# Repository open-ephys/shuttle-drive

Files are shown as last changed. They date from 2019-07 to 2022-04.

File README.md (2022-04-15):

# Shuttle-drive, the next gen. tetrode drive implant 

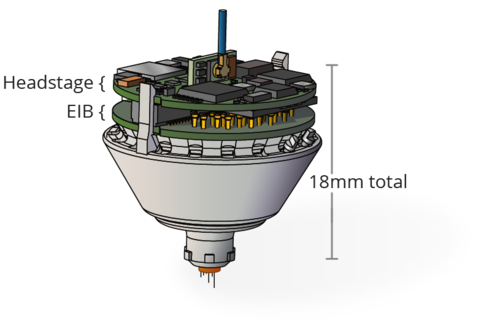
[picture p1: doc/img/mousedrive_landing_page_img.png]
mouse drive


Tetrode arrays are the gold-standard method for neural recordings in many studies with behaving animals, especially for deep structures and chronic recordings. Here we outline an improved drive design for use in freely behaving animals. Our design makes use of recently developed technologies to reduce the complexity and build time of the drive while maintaining a low weight. The design also presents an improvement over many existing designs in terms of robustness and ease of use. We describe two variants: a 16 tetrode implant weighing ∼2 g for mice, bats, tree shrews and similar animals, and a 64 tetrode implant weighing ∼16 g for rats, and similar animals.These designs were co-developed and optimized alongside a new class of drive-mounted feature-rich amplifier boards with ultra-thin RF tethers, as described in an upcoming paper (Newman, Zhang et al., in prep). This design significantly improves the data yield of chronic electrophysiology experiments.

### Features

__64-Channel Drive__
- Channel count (small version): 18 drive mechanisms and up to 64 ephys channels per drive.
- Weight: ~2g for 16 tetrode drives.
- Build time:  < 1 day (small version).
- 4.5 mm travel distance, fully enclosed mechanism, low center of gravity. 

__256-Channel Drive__
- Channel count: 64 drive mechanisms and up to 256 ephys channels per drive.
- Weight: ~15g for 64 tetrode drives.
- 10 mm travel distance, fully enclosed mechanism, low center of gravity)

### Components & Availability

Ready-made drive components are available for purchase at the Open Ephy store
[here](http://www.open-ephys.org/drive-implant). All profits go towards
supporting the Open Ephys initiative if, and only if, parts are bought via this
store.

The drive consists of the following components:
- A 3d printed drive body
- 3d printed drive shuttles
- Polymicro (polyimide-coated quartz) shuttle tubes

These components can be purchased as bundle on our store:
- Polyimide tubes to make guide tube arrays 
- Custom screws (reusable) 
- Electrode interface boards (EIB) are available for 64 channel or 32 channel Omnetics headstages 

To assemble the drive and adjust tetrodes, an assembly jig and screwdriver are
needed. Both are available on the Open Ephys store.
- Assembly jig 
- Custom screwdriver 

### Building instructions & Documentation

For a quick initial overview, we provide a brief video detailing all the major steps of assembling the drive: [Assembly steps on youtube](https://www.youtube.com/watch?v=VBs4_pltE6o&feature=emb_logo).

The main documentation and building instructions are in the accompanying manuscript:

[Voigts et al.  An
easy-to-assemble, robust, and lightweight drive implant for chronic tetrode
recordings in freely moving animals](https://www.biorxiv.org/content/10.1101/746651v1). We recommend this manuscript as a starting point because it covers a lot of possible issues and goes into considerable detail on how to achieve the best results.

**A structured, up to date documentation is on the Open Ephys docs**: [https://open-ephys.github.io/shuttledrive-docs/](https://open-ephys.github.io/shuttledrive-docs/)

We also provide a [spreadsheet with step-by-step instructions](https://docs.google.com/spreadsheets/d/1qlOEyMCUptONbd9Ac4yKie1TxPHhV1puGx7GZTR9lvk/edit?usp=sharing), provided by Dimitra Vardalaki.

Finally, we encourage contributions from anyone, particularly additional information on variants and build instructions in nay form, including pull-requests or links to external documentation.

### Parts List / Bill of Materials
The bill of materials is located on this [google sheet](https://docs.google.com/spreadsheets/d/1LGhZMRnzcyo_r0Nunrh_lfmy5V0NHia-rGRHAYOWq4o/edit?usp=sharing)

### Citing this Work 
When using the Open Ephys shuttle drive implants, please cite the paper:

An easy-to-assemble, robust, and lightweight drive implant for chronic tetrode recordings in freely moving animals
J Voigts, JP Newman, MA Wilson, MT Harnett
Journal of Neural Engineering 17 (2), 026044
 [Link jne](https://iopscience.iop.org/article/10.1088/1741-2552/ab77f9/meta) [Link biorxiv](https://www.biorxiv.org/content/10.1101/746651v1) 

## License
Copyright Jakob Voigts, Jonathan P. Newman 2020.

<br />This work is licensed under a <a rel="license" href="http://creativecommons.org/licenses/by-nc-sa/3.0/igo/">Creative Commons Attribution-NonCommercial-ShareAlike 3.0 IGO License</a>.

If your are interested in obtaining a license to sell this device, please contact us at https://open-ephys.org/contact

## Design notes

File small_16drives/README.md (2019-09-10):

# shuttleDrive-16

Mouse version of the next generation tetrode drive implant.

mouse drive

This is the variant for 16 drives.
The bill of materials can be found at https://docs.google.com/spreadsheets/d/1LGhZMRnzcyo_r0Nunrh_lfmy5V0NHia-rGRHAYOWq4o/edit?usp=sharing

Additional assembly instructions can be found at https://docs.google.com/spreadsheets/d/1qlOEyMCUptONbd9Ac4yKie1TxPHhV1puGx7GZTR9lvk/edit?usp=sharing

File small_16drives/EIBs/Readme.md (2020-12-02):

# Omnetics EIBs for Open Ephys Shuttledrive

**(Deprecated)** We do not recommend using these EIBs any longer, instead consider switching to the hirose based EIBs (https://open-ephys.org/drive-implant/64-channel-eib-lyfw2) together with the newer low-profile headstage https://open-ephys.org/acquisition-system/low-profile-spi-headstage-64ch. In the longer term, consider using the upcoming ONIX system with this drive.

For the 64 channel variant, extra care is required to keep a precise alignment between the two omnetics connectors.

The EIB for the ONIX system and the SPI compatible low profile hedstage are found in the ONIX system repository at https://github.com/jonnew/ONIX/tree/main/eib-64

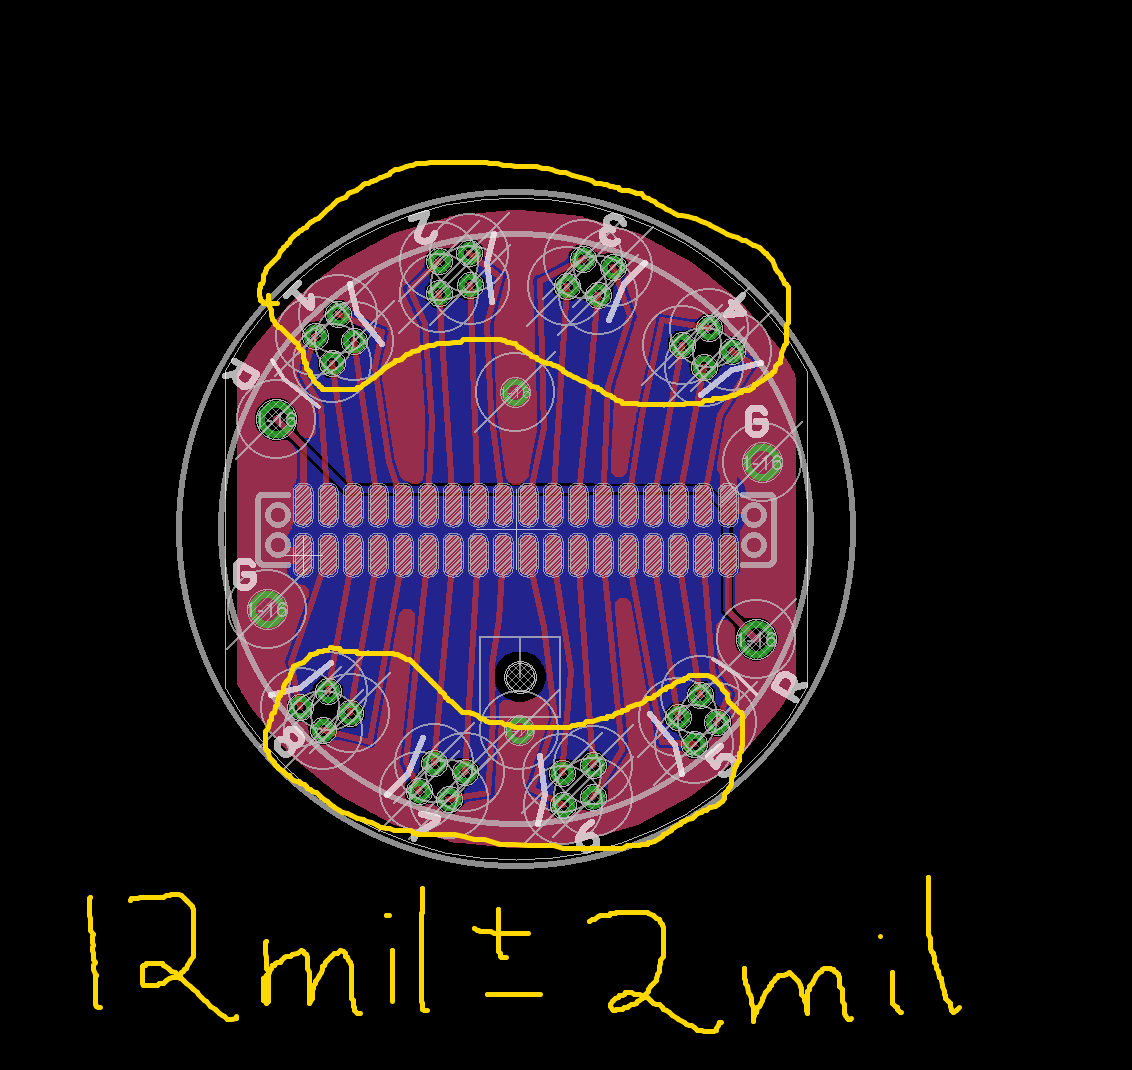
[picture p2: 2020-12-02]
small_16drives/EIBs/eib-32-intan-hs/gerber_panel/README_HOLE_SIZES.png

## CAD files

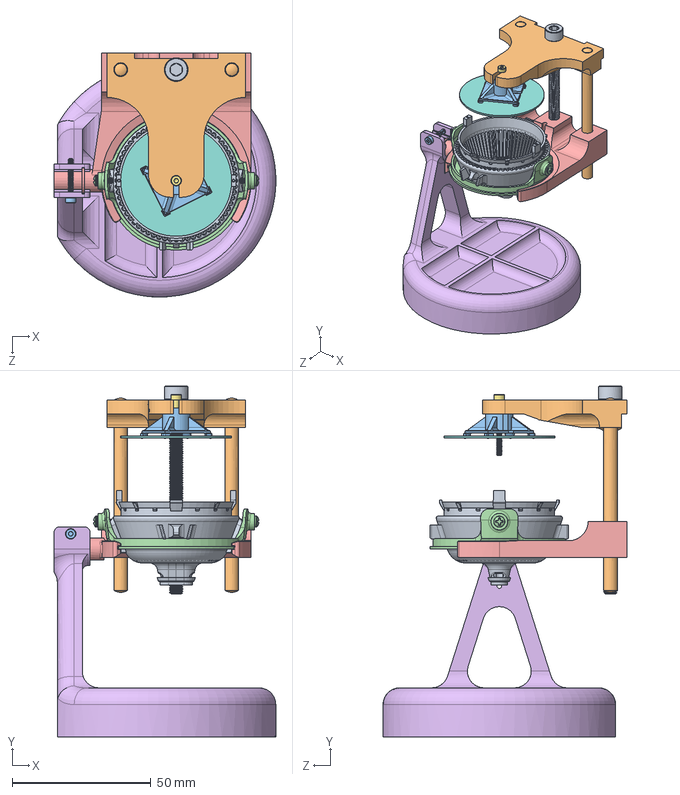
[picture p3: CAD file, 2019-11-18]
large_64drives/assembly-jig/rat_jig_assembly.SLDASM
79.9 x 126.4 x 87.9 mm
rat_shuttle_drive_body_bilateral_vta
eib_holder_top
eib256_holder
drive_body_holder_inner_ring
drive_body_holder_outer_ring
jig_base_big_rat
socket head cap screw_am
eib_standin
91290A201_BLACK-OXIDE CLASS 12.9 SOCKET HEAD CAP SCREW
91595A399_METRIC ALLOY STEEL DOWEL PIN x 2
91292A835_TYPE 18-8 SS SOCKET HEAD CAP SCREW
92005A023_METRIC PAN HEAD PHILLIPS MACHINE SCREW x 2

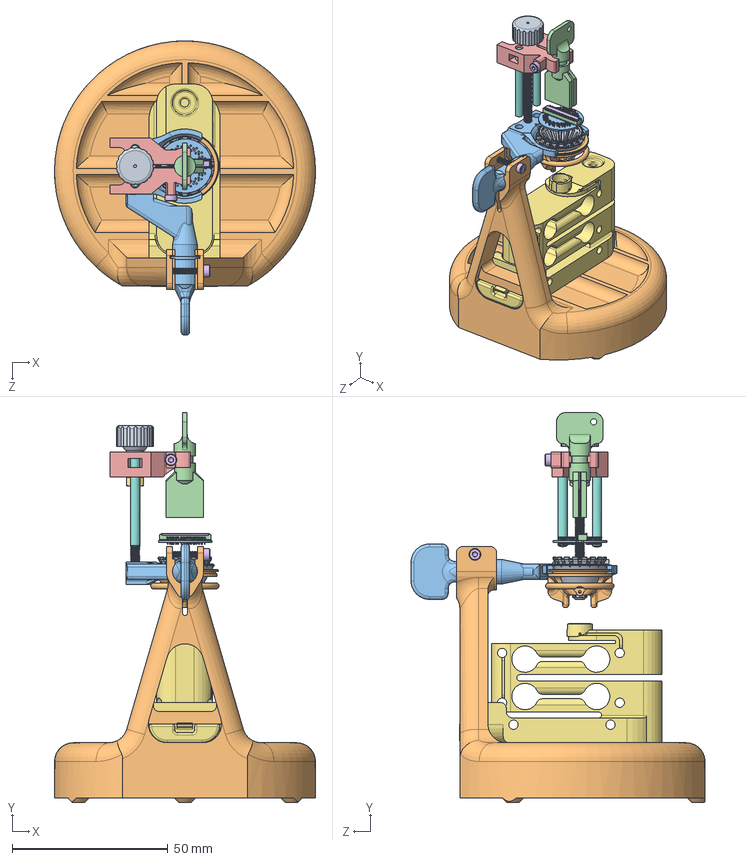
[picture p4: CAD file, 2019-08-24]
small_16drives/assembly_jig/mouse_jig_assembly.SLDASM
83.8 x 125.3 x 94.5 mm
shuttle_drive_body
drive_holder_inner
drive_holder_bottom
eib_holder_inner_two_omnetics
eib_holder_top
socket head cap screw_am x 3
hex nut style 2_am
dowel pin_a_jis x 2
screw_thumbwheel
jig_base_big_rat
eib_pcb_64ch
DF40C(2.0)-70DS_hirose_df40_receptacle
neuralynx_gold_pin_small x 64
DF40C-70DP_hirose_df40_plug
plating_jig_baseSLDPRT

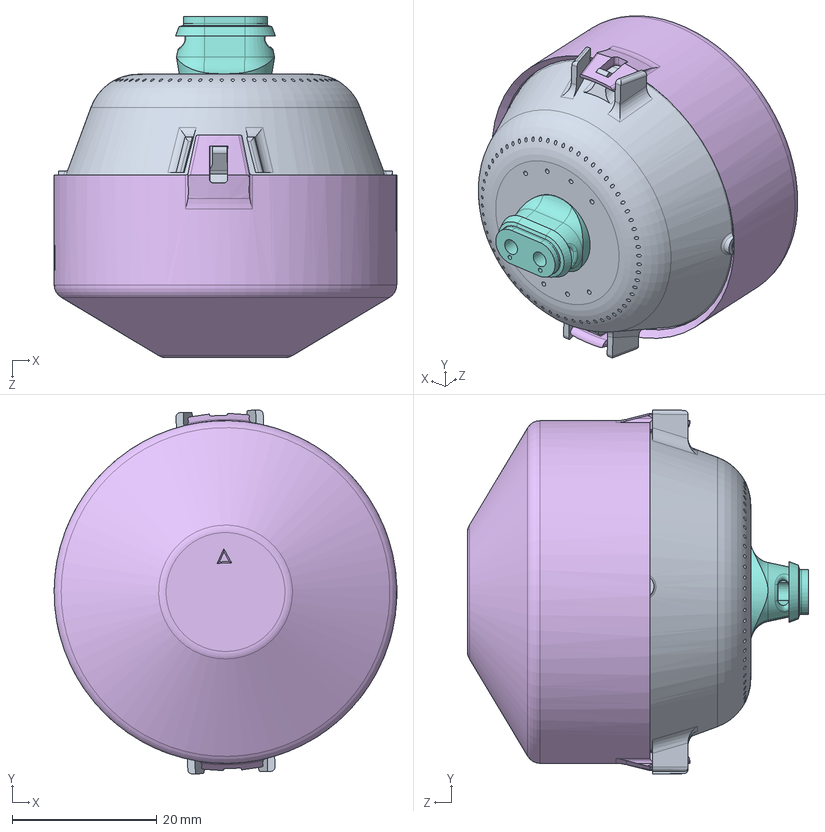
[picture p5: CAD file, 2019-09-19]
large_64drives/rat_drive_assembly_electronics.SLDASM
47.4 x 50.3 x 47.2 mm
rat_shuttle_drive_no_cannula
rat-eib
rat-headstage
CONSMA001-ND
rat_headstage-retainer
rat_cap_sma
rat_drive_shuttle_short x 64
rat_shuttle_drive_insert_bilateral_vta

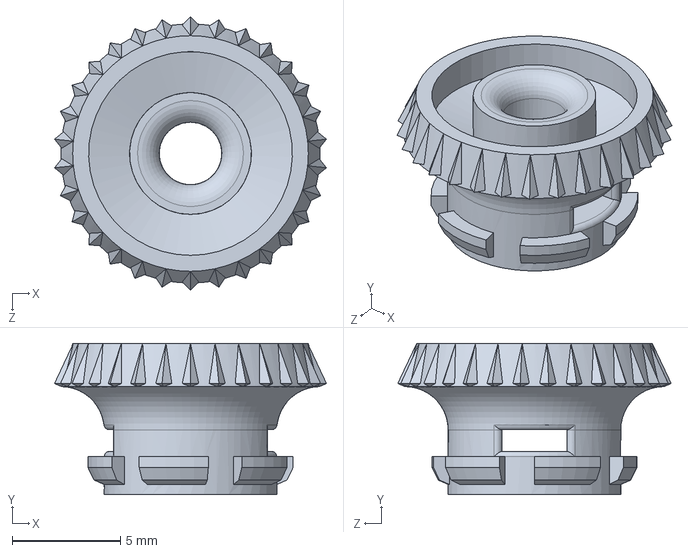
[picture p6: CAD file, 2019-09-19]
large_64drives/rat_shuttle_drive_insert_central.SLDPRT
12.6 x 7.00 x 12.7 mm

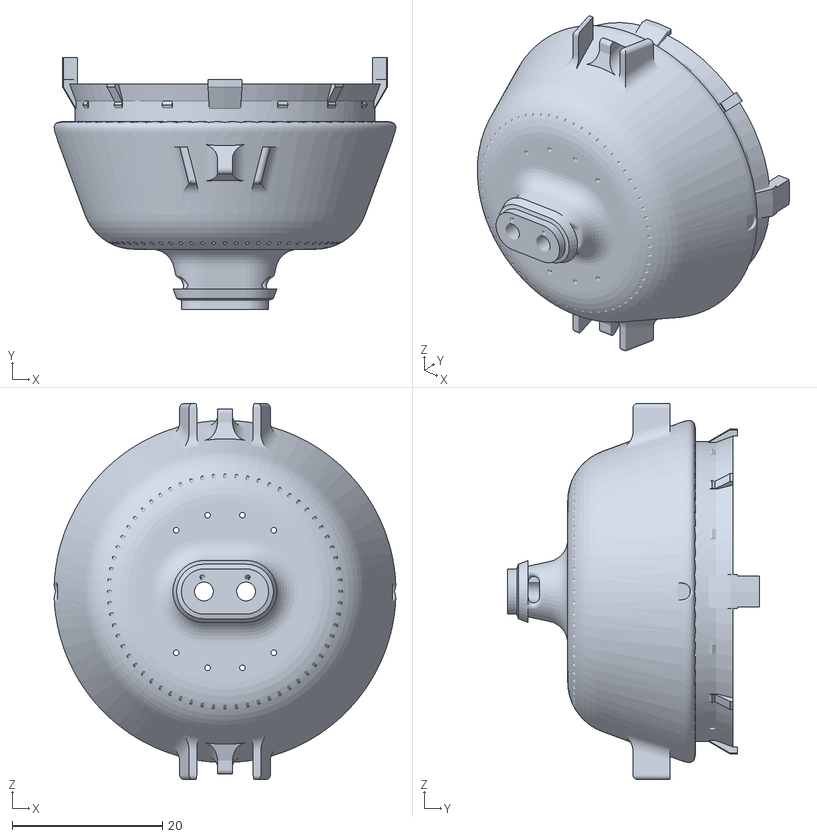
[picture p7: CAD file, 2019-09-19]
large_64drives/stl/rat_shuttle_drive_body_bilateral_vta.STL
45.4 x 33.5 x 50.0

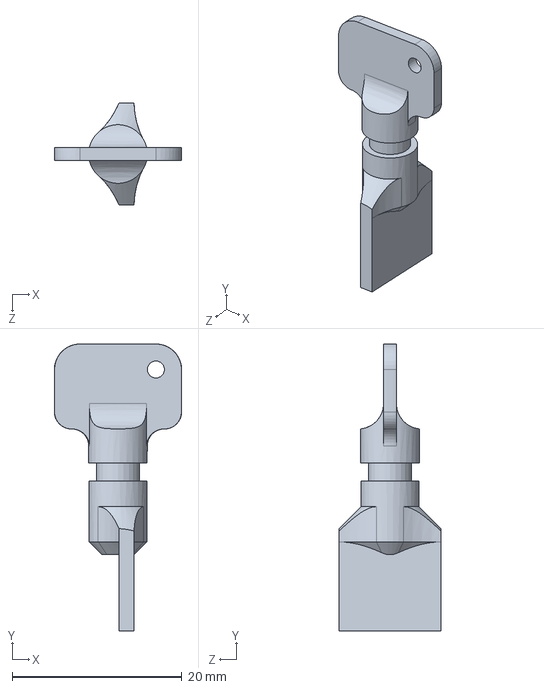
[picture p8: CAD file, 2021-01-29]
small_16drives/assembly_jig/eib_holder_inner_hirose_1mm_offset.SLDPRT
15.0 x 33.8 x 12.0 mm

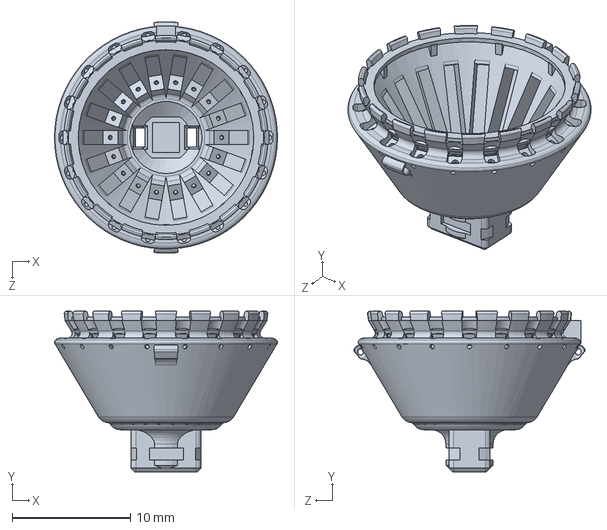
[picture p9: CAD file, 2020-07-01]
small_16drives/drive_small/drive_body_variants/shuttle_drive_body_bilateral_square_3_5mm_gap.SLDPRT
18.9 x 13.6 x 19.5 mm

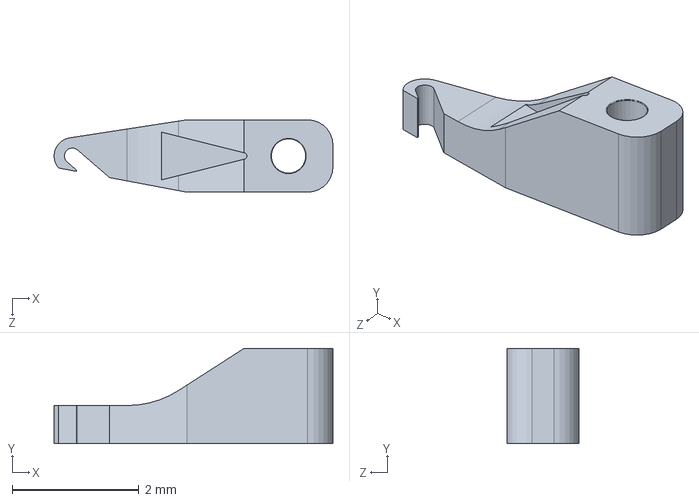
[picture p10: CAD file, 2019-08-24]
small_16drives/drive_small/drive_shuttle.SLDPRT
4.39 x 1.50 x 1.14 mm

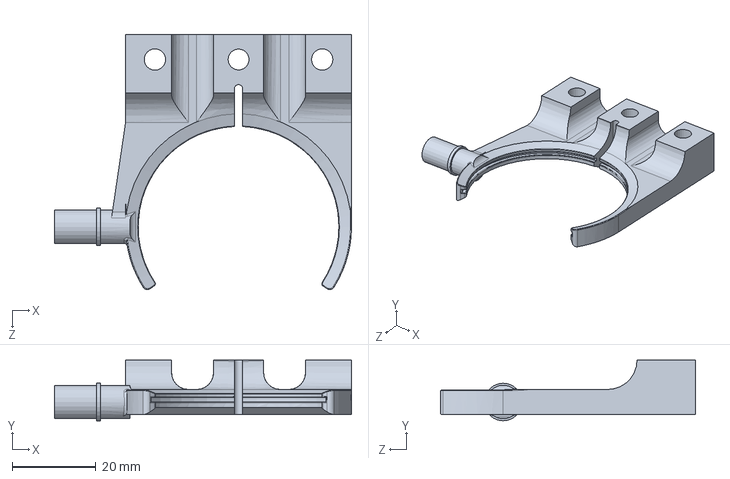
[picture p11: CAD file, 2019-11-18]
large_64drives/assembly-jig/drive_body_holder_outer_ring.SLDPRT
71.0 x 14.5 x 61.0 mm

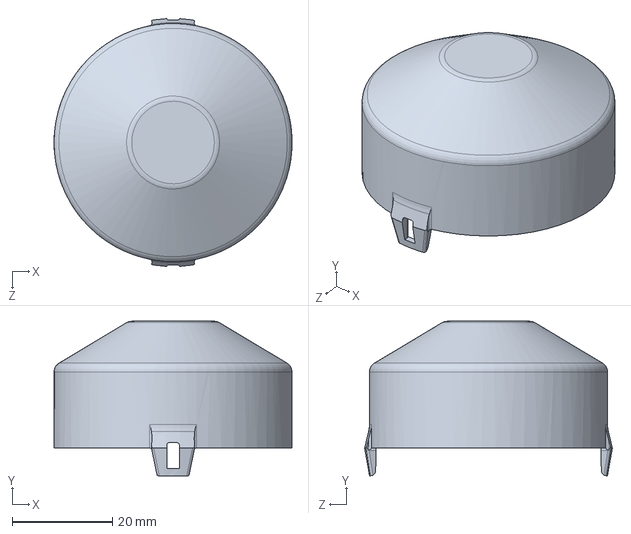
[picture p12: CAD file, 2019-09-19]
large_64drives/rat_cap_sma.SLDPRT
47.4 x 30.8 x 49.3 mm

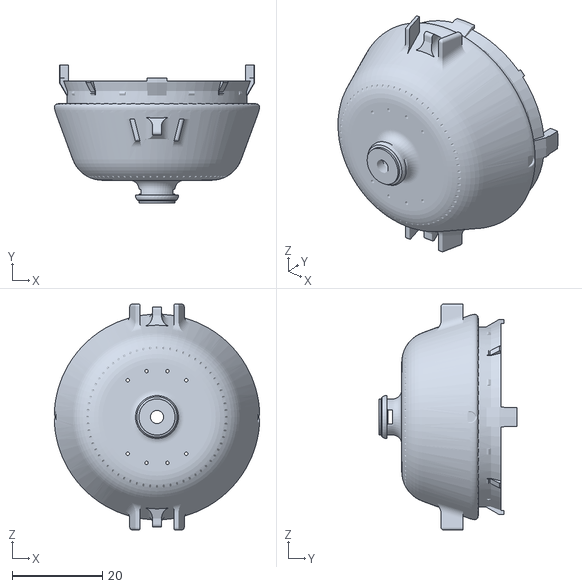
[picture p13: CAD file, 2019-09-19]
large_64drives/stl/rat_shuttle_drive_central.STL
45.4 x 30.5 x 50.0

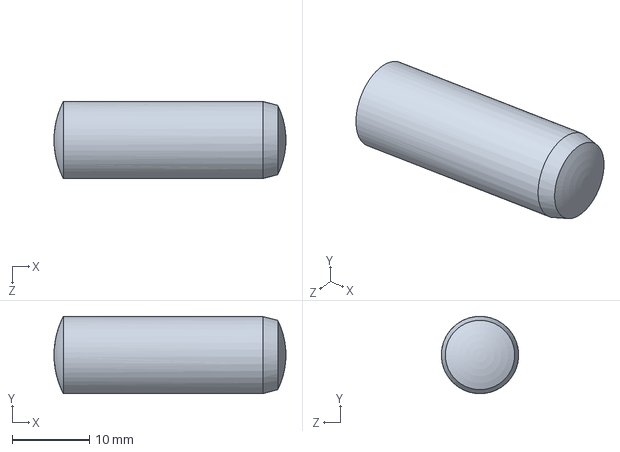
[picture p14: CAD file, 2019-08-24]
small_16drives/assembly_jig/dowel pin_a_jis.sldprt
30.0 x 10.0 x 9.99 mm

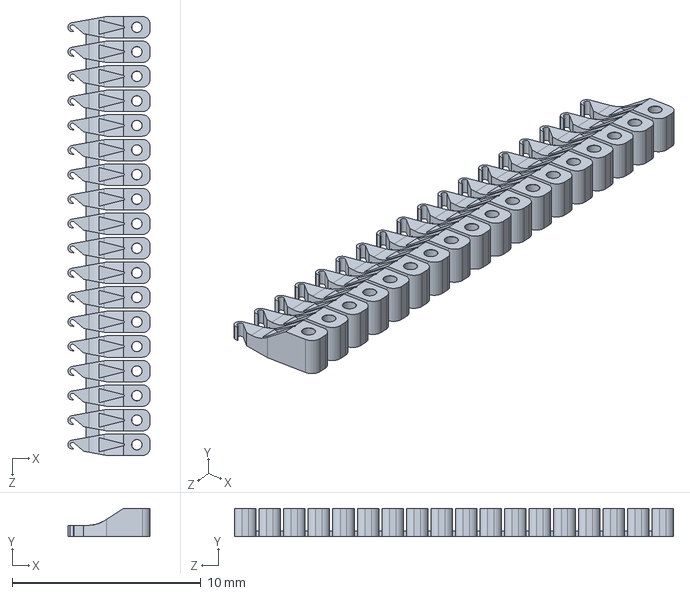
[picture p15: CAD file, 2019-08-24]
small_16drives/drive_small/not_needed_for_drives/shuttle_drive_shuttle_hook_vary_thickness.SLDPRT
4.35 x 1.50 x 23.2 mm

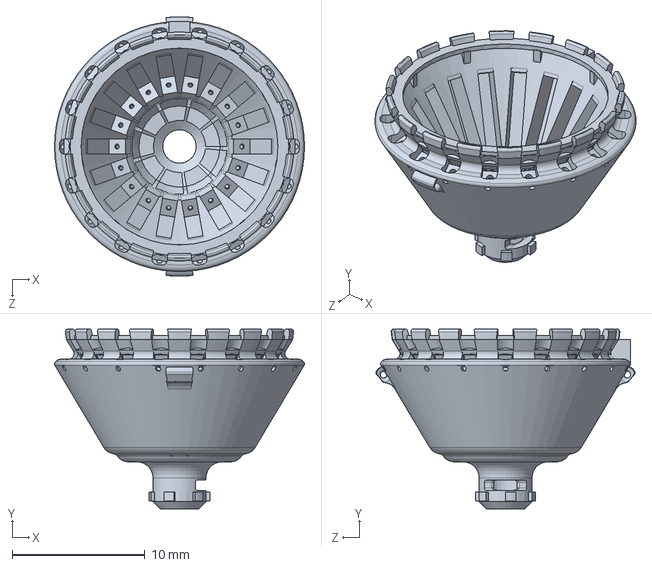
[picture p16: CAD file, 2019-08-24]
small_16drives/drive_small/shuttle_drive_body.SLDPRT
18.9 x 13.6 x 19.5 mm

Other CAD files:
small_16drives/assembly_jig/stl_order/eib_holder_inner_hirose_2mm_offset.STL
small_16drives/assembly_jig/stl_order/eib_holder_inner_hirose_1mm_offset.STL
large_64drives/assembly-jig/50mm_4mm_dowel.SLDPRT
large_64drives/CONSMA001-ND.SLDPRT
large_64drives/assembly-jig/80mm_6mm_dowel.SLDPRT
large_64drives/assembly-jig/91290A201_BLACK-OXIDE CLASS 12.9 SOCKET HEAD CAP SCREW.SLDPRT
large_64drives/assembly-jig/91292A835_TYPE 18-8 SS SOCKET HEAD CAP SCREW.SLDPRT
large_64drives/assembly-jig/91595A399_METRIC ALLOY STEEL DOWEL PIN.SLDPRT
large_64drives/assembly-jig/92005A023_METRIC PAN HEAD PHILLIPS MACHINE SCREW.SLDPRT
large_64drives/assembly-jig/drive_body_holder_inner_ring.SLDPRT
large_64drives/assembly-jig/eib256_holder.SLDPRT
large_64drives/assembly-jig/eib_holder_top.SLDPRT
large_64drives/assembly-jig/eib_standin.SLDPRT
large_64drives/assembly-jig/jig_base_big_rat.SLDPRT
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

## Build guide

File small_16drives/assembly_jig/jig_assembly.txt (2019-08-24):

Assembly jigs:

The jigs are made up of various 3d-printed components, and a few screws and dowels.
Some components can be printed with relatively low-resolution processes (ideally sintered nylon powder at !0.12mm layer height, but high quality fused plastic could also work), while some required medium-resolution printing (Multijet Modeling or Stereolithography, with around 0.03mm layer thickness).
The components are:
 
Base (low quality) - the base everything else sits on. Shared bwteeen the rat and the mouse design. All other componets differ between the two variants.

Outer drive holder (medium quality*) - connects to the base and holds the drive holder.

Inner drive holder (medium quality*) - sits inside the outer drive holder and directly holds the drive body, allowing it to rotate around its major axis.

Inner EIB holder (medium quality*) - holds the EIB, allowing it to rotate. This part may have to be customized to fit the desired type of EIB.

Outer EIB holder (medium quality*) - Holds the inner EIB holder.

Manual adjustment know (low quality) to amke adjusting the long screw easier - hand-adjustible screws can be used alternatively, or tools can be used ot adjust mechnaism distance.

* for the rat variant, all parts can be printed with a lower quality process in some cases.

The outer EIB and drive holders form a linear slide that allows adjustments of their distance to each other. This slide is formed by two dowels and a screw.

BOM (part numbers are Mcmaster-Carr):

both variants
4x parts medium quality 3d printing, separate for rat and mouse drives, the rat variant has less stringent resolution requirements.
1x part low quality 3d printing.
1x lead disc, 1/2" Thick, 2-3/4" OD, #	90385K22 $19
1x M2 screw and nut for clamping drive holder to base. # 	91292A032 , $6 for 10
1x plastics compatible lubricant for bearing surfaces (optional) 

Mouse variant
2x M3 40mm dowels, # 91585A426, $10 for 25
1x M3 40mm screw, fully threaded, # 	91292A024, $ 3 for 25
1x M3 washer (for gluing against top slide as retainer), # 	90965A130, $3 for 100
1x M1 screw (for holding in drive especially securely, optional)

Rat variant
2x M5 70mm dowels
1x M5 70mm screw, fully threaded
2x M3x15mm screws for holding drive to drive holder
1x M2xXXmm screw, non-threaded below screw head, to make IEB holder pin
1x M2 nut for manual adjustment, either knurled, or wing nut.

Assembling the assembly jigs: 

- Glue lead disc into base with epoxy, and cover entire base surface with epoxy, so that no lead remains exposed.
- The dowels should slide freely trough the lower side of the slide / trough the outher drive holder, and the adjustment screw should freely slide trough the hold in the outer EIB holder. If not, these holes can be drilled out.
- If needed, the dowels can be glued into one side of the linear slide by using the provided glue pockets, and similarly, threads for the adjustment screw can be formed by lightly oiling the screw, turning it trough the lower part of the slide (the outer drive holder) and the filling the provided cavity with epoxy.
- Insert lower EIB holder into the base, and add clamping screw and nut. 
- (For the mouse variant) insert inner EIB holder into outer EIB holder and add clamping screw and nut.
- Glue clamping nuts to the 3d printed parts with epoxy in their clamped state.
- Insert slide with EIB holder into the outer drive holder and verify proper function of the distance adjustment.

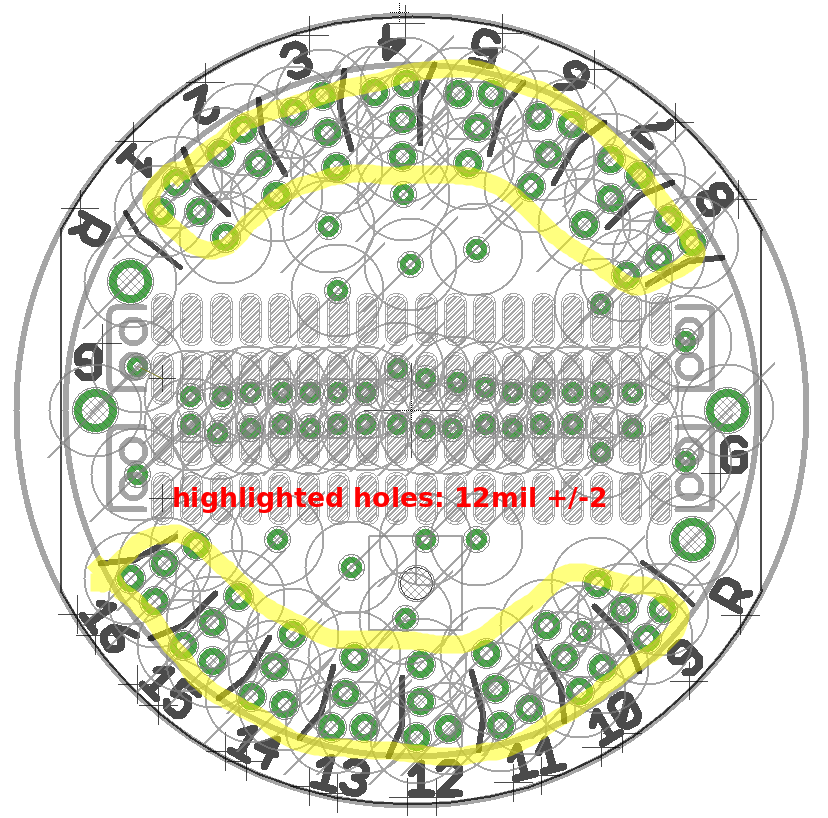
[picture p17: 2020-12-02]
small_16drives/EIBs/eib-64-intan-hs/manufacturing_instructions_speedy.png

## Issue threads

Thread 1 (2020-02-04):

Using the old flexDrive 64-channel EIB

teristam, 2020-02-04:
Hi,

Our lab has a bunch of 64-channel EIB for flexDrive lying around but we would like to try the new shuttle drive. May I ask if the old EIBs are still usable with the new shuttle drive?

Thanks!

jvoigts, 2020-02-04:
Hi,
no the old EIBs will not fit the new drives. They are both too large, and the gold pins are too far out on the periphery of the pcb. If you want to recover the omnetics connectors you can hold the old eib by the connector with forceps and heat the pcb from below with a hot air soldering tool until it falls down. Re-soldering them onto the new eib pcbs however is a bit tricky due to the close spacing.

Closed 2020-02-04.

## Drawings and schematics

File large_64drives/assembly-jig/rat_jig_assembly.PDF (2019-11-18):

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

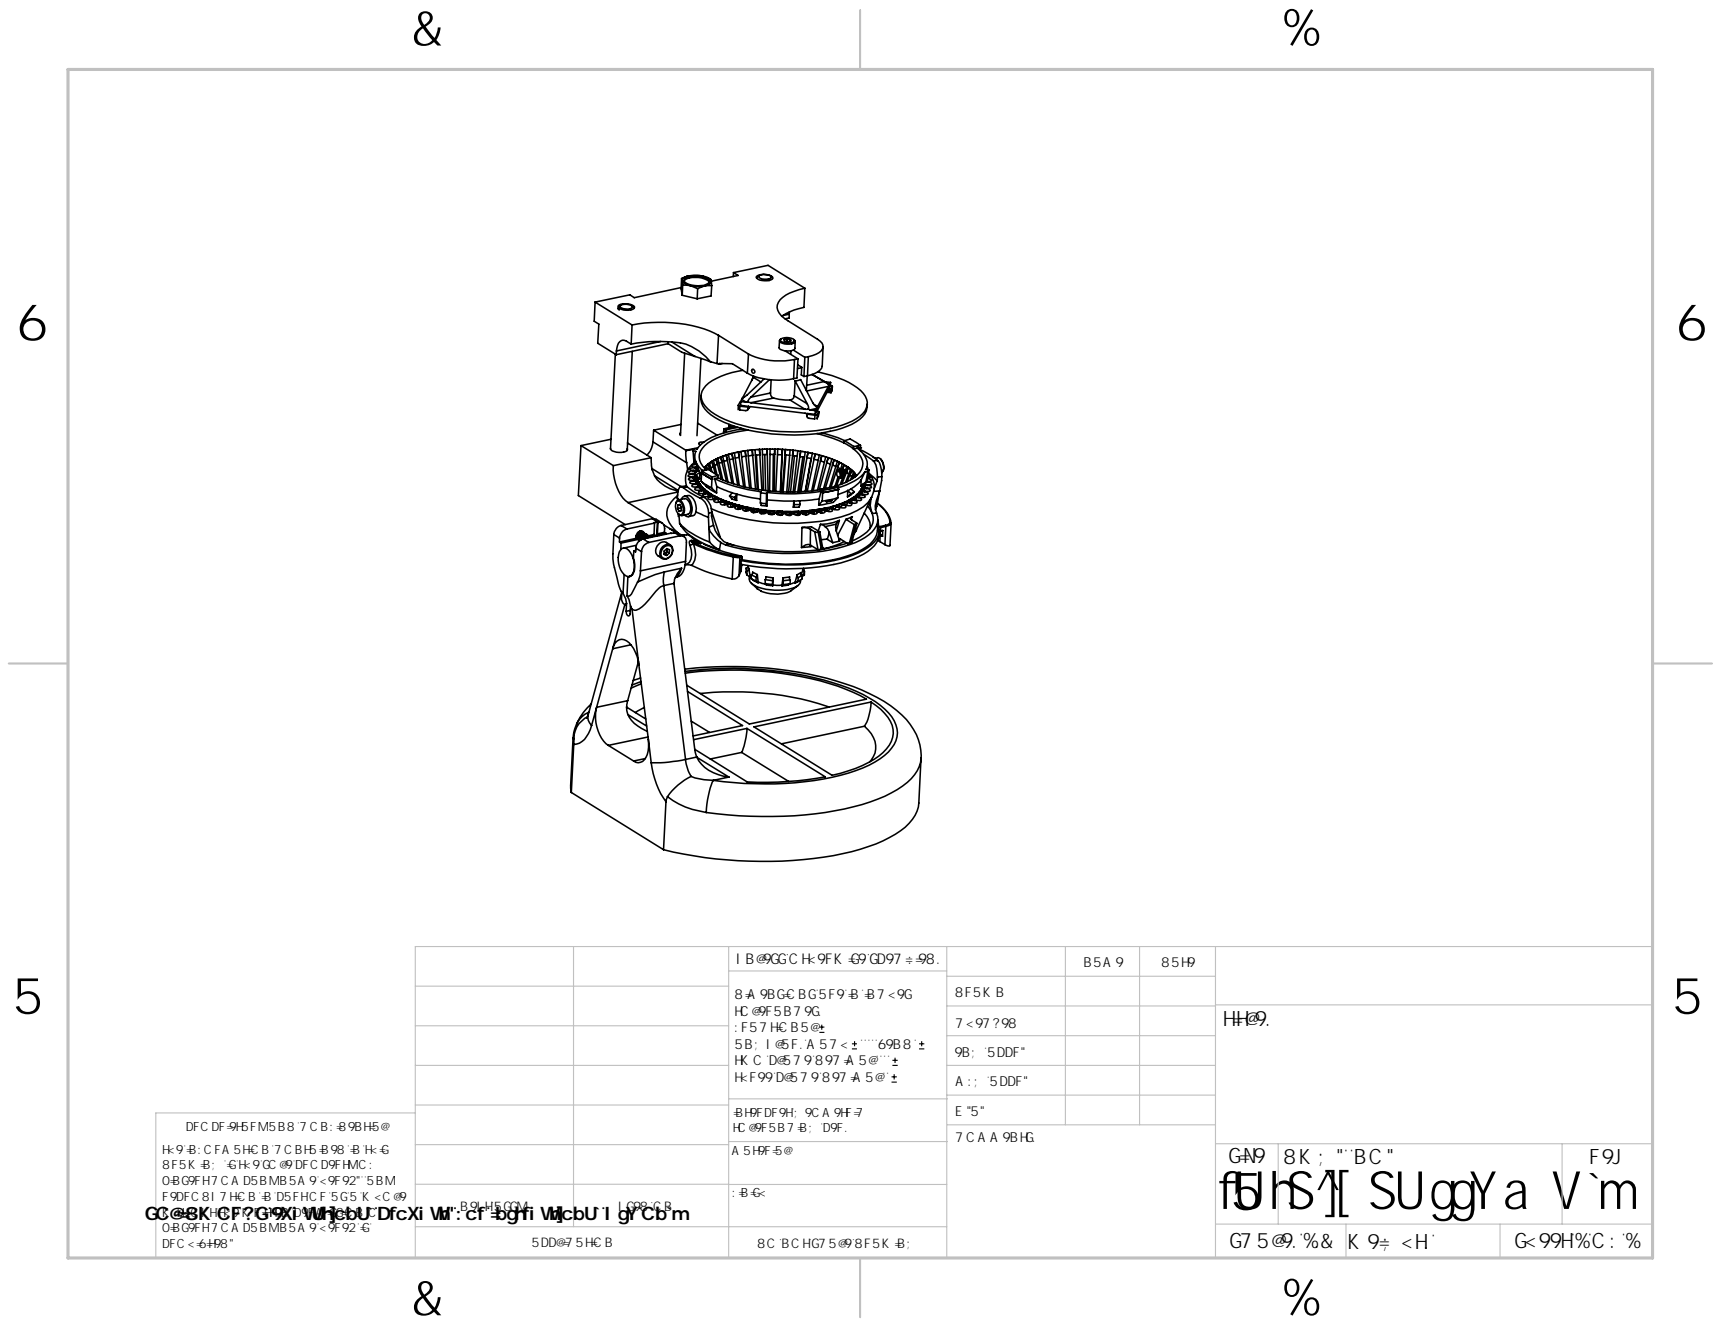
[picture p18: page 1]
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

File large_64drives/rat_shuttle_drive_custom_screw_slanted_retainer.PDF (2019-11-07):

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

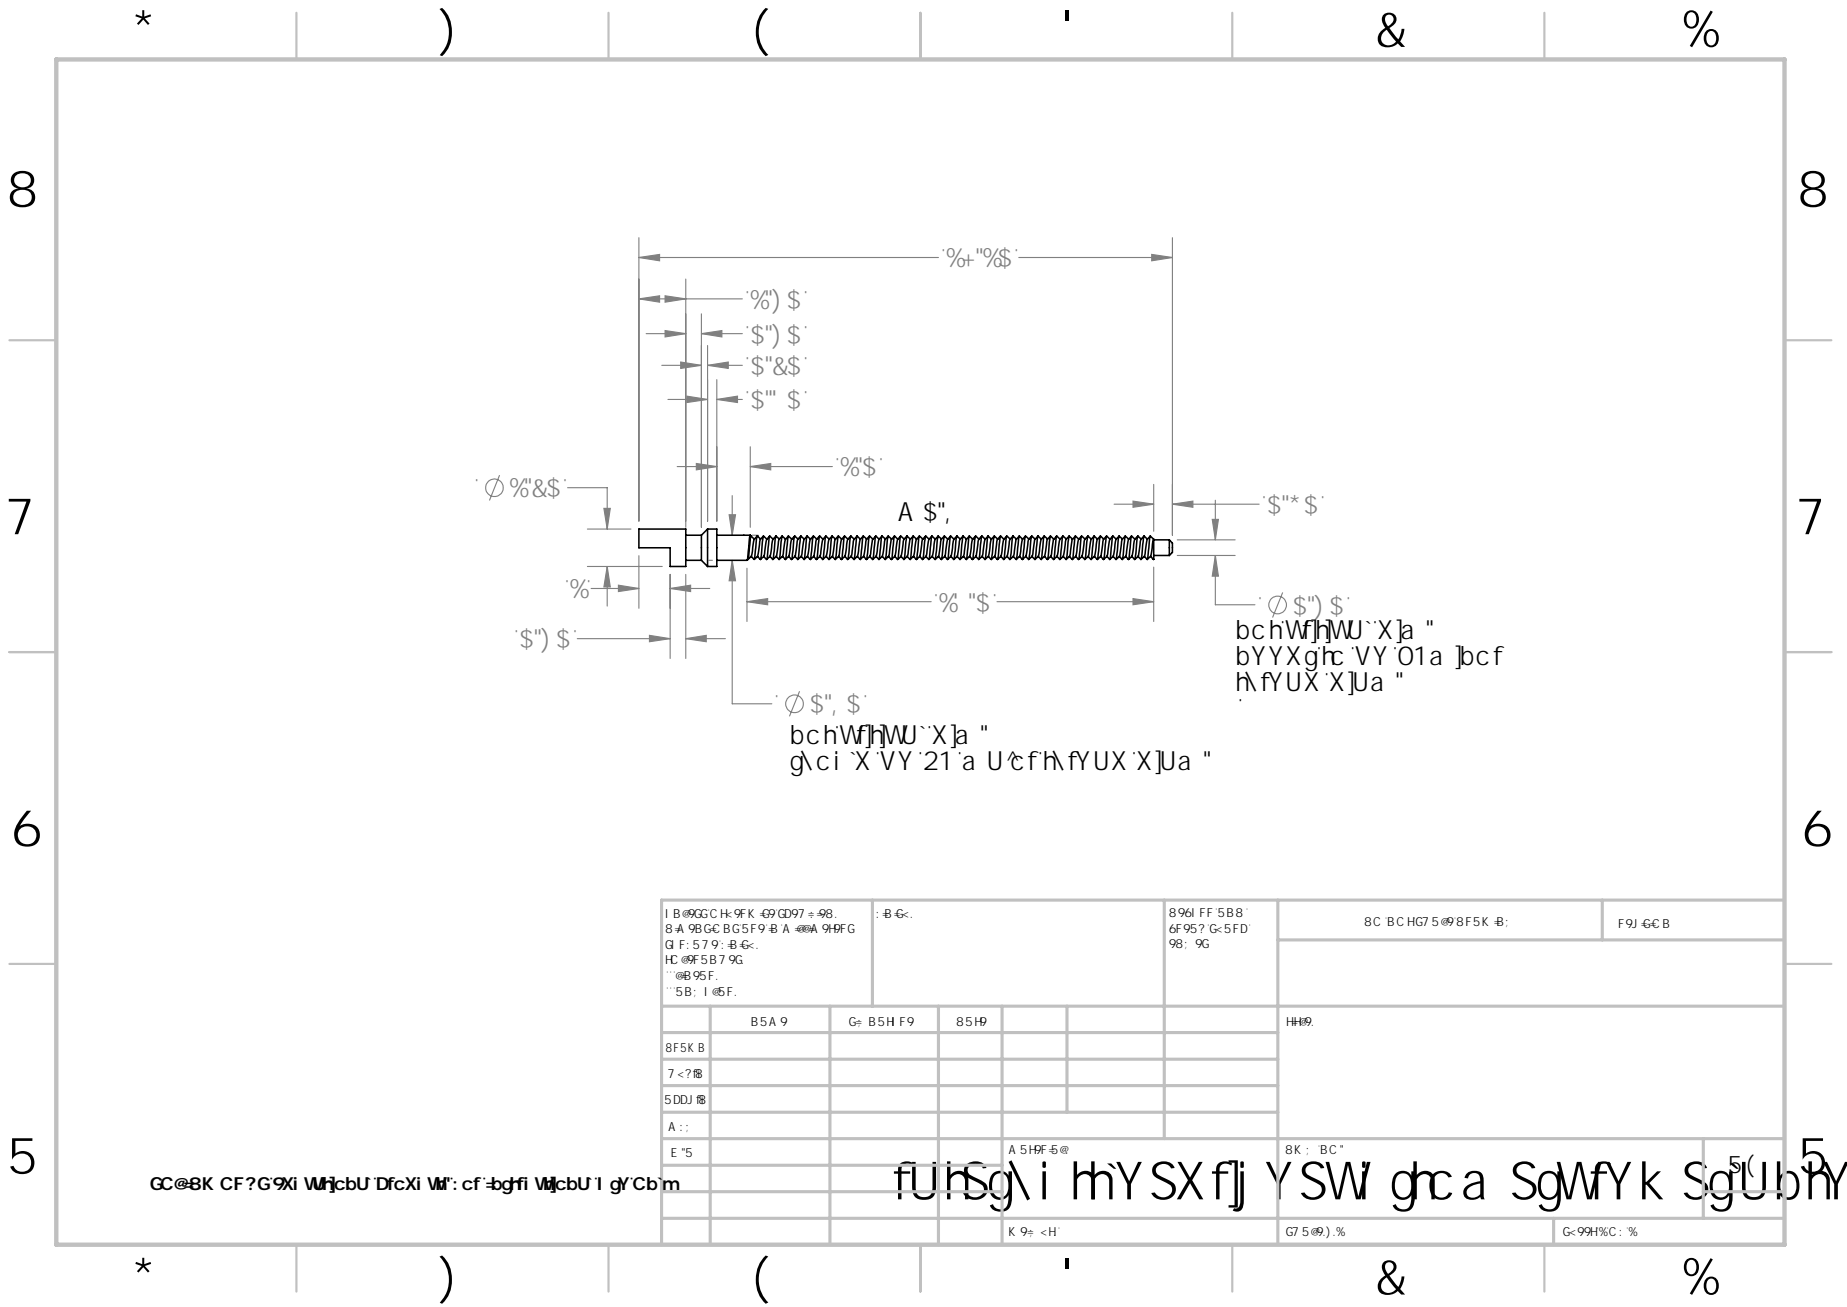
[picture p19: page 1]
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

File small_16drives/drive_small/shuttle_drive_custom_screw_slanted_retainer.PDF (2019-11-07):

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

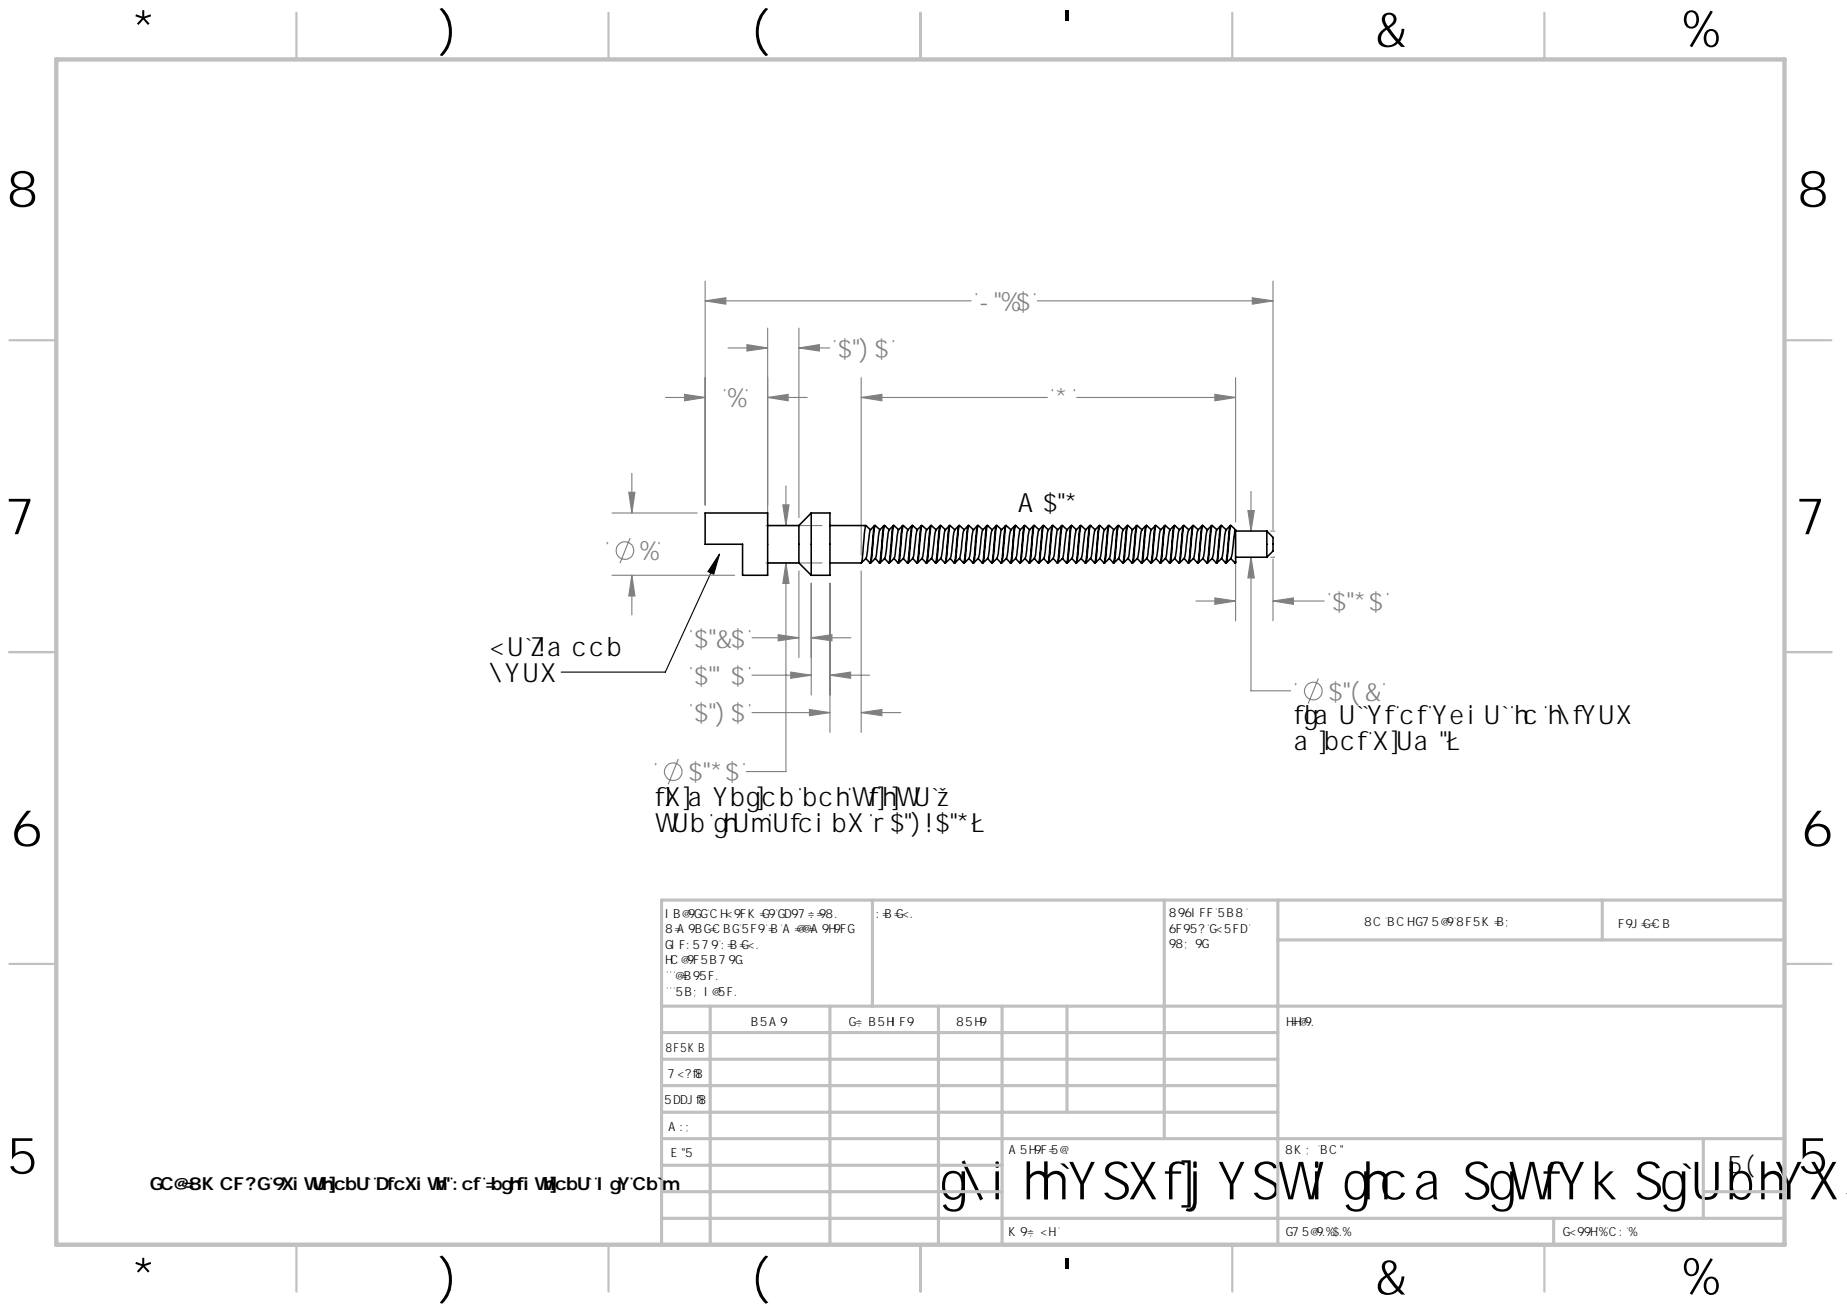
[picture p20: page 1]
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

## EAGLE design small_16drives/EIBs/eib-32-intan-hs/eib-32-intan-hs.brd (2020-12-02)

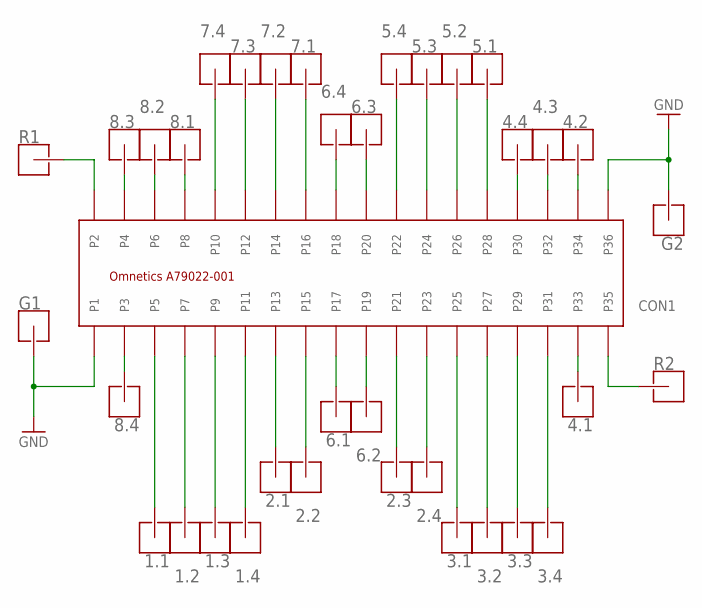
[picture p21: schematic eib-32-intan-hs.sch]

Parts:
1.1, 1.2, 1.3, 1.4, 2.1, 2.2, 2.3, 2.4, 3.1, 3.2, 3.3, 3.4, 4.1, 4.2, 4.3, 4.4, 5.1, 5.2, 5.3, 5.4, 6.1, 6.2, 6.3, 6.4, 7.1, 7.2, 7.3, 7.4, 8.1, 8.2, 8.3, 8.4: HOLE_L_G_PIN_V7; LARGE_GOLD_PIN_V7
CON1: A79022-001_MALESMD; A79026-001_MALE
G1, G2: HOLE_L_G_PIN_V7; LARGE_GOLD_PIN_V7
R1, R2: HOLE_L_G_PIN_V7; LARGE_GOLD_PIN_V7

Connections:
GND: CON1.P1, CON1.P36, G1.P$1, G2.P$1
unnamed: 1.1.P$1, CON1.P5
unnamed: 1.2.P$1, CON1.P7
unnamed: 1.3.P$1, CON1.P9
unnamed: 4.1.P$1, CON1.P33
unnamed: 4.3.P$1, CON1.P32
unnamed: 4.2.P$1, CON1.P34
unnamed: 1.4.P$1, CON1.P11
unnamed: 4.4.P$1, CON1.P30
unnamed: 6.1.P$1, CON1.P17
unnamed: 6.2.P$1, CON1.P19
unnamed: 6.3.P$1, CON1.P20
unnamed: 7.3.P$1, CON1.P12
unnamed: 2.1.P$1, CON1.P13
unnamed: 2.2.P$1, CON1.P15
unnamed: 2.3.P$1, CON1.P21
unnamed: 2.4.P$1, CON1.P23
unnamed: 3.1.P$1, CON1.P25
unnamed: 3.2.P$1, CON1.P27
unnamed: 3.3.P$1, CON1.P29
unnamed: 3.4.P$1, CON1.P31
unnamed: 6.4.P$1, CON1.P18
unnamed: 8.4.P$1, CON1.P3
unnamed: 8.3.P$1, CON1.P4
unnamed: 8.2.P$1, CON1.P6
unnamed: 8.1.P$1, CON1.P8
unnamed: 7.2.P$1, CON1.P14
unnamed: 7.1.P$1, CON1.P16
unnamed: 7.4.P$1, CON1.P10
unnamed: 5.1.P$1, CON1.P28
unnamed: 5.2.P$1, CON1.P26
unnamed: 5.4.P$1, CON1.P22
unnamed: 5.3.P$1, CON1.P24
unnamed: CON1.P2, R1.P$1
unnamed: CON1.P35, R2.P$1

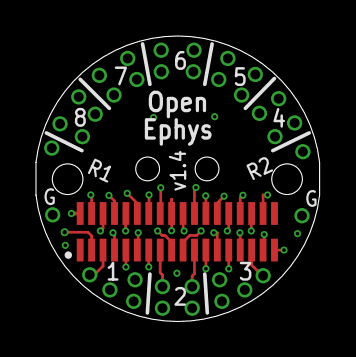
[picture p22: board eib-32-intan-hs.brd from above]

Board: 4 copper layers, 15.8 x 15.9 mm, 37 parts (0 on the bottom side), 35 nets.

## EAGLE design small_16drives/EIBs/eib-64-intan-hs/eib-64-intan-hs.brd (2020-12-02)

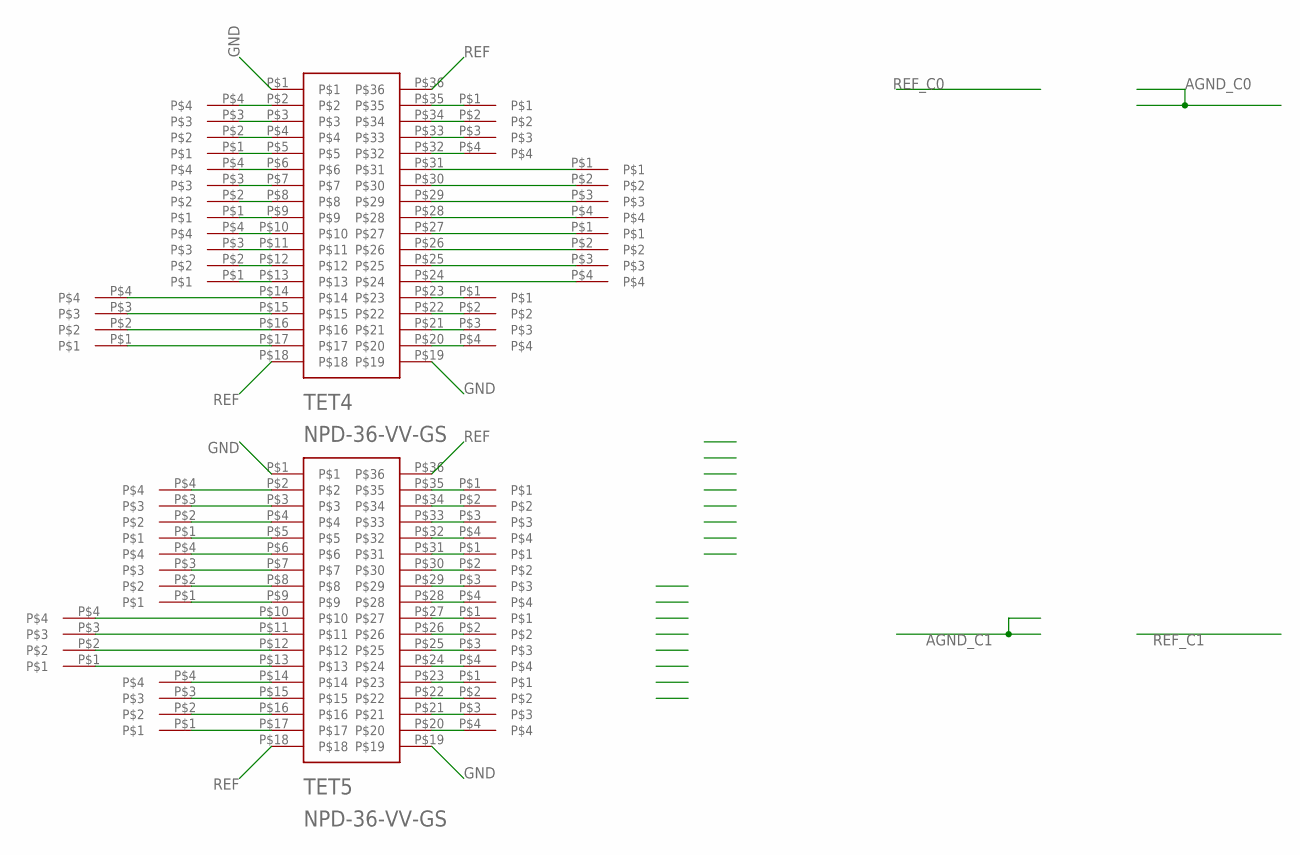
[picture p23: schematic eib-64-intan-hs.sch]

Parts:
TET0: 0; TET32
TET1: 1; TET32
TET2: 2; TET32
TET3: 3; TET32
TET4, TET5: NPD-36-VV-GS
TET8: 8; TET32
TET9: 9; TET32
TET10: 10; TET32
TET11: 11; TET32
TET12: 12; TET32
TET13: 13; TET32
TET14: 14; TET32
TET15: 15; TET32
TET20: 20; TET32
TET21: 21; TET32
TET22: 22; TET32
TET23: 23; TET32

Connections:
GND: TET4.P$1, TET4.P$19, TET5.P$1, TET5.P$19
unnamed: TET5.P$6, TET9.P$4
unnamed: TET5.P$2, TET8.P$4
unnamed: TET5.P$3, TET8.P$3
unnamed: TET5.P$4, TET8.P$2
unnamed: TET5.P$5, TET8.P$1
unnamed: TET5.P$7, TET9.P$3
unnamed: TET5.P$8, TET9.P$2
unnamed: TET5.P$9, TET9.P$1
unnamed: TET5.P$10, TET14.P$4
unnamed: TET5.P$11, TET14.P$3
unnamed: TET5.P$28, TET11.P$4
unnamed: TET5.P$27, TET12.P$1
unnamed: TET5.P$26, TET12.P$2
unnamed: TET5.P$25, TET12.P$3
unnamed: TET5.P$24, TET12.P$4
unnamed: TET5.P$23, TET13.P$1
unnamed: TET5.P$22, TET13.P$2
unnamed: TET5.P$21, TET13.P$3
unnamed: TET5.P$35, TET10.P$1
unnamed: TET5.P$34, TET10.P$2
unnamed: TET5.P$33, TET10.P$3
unnamed: TET5.P$32, TET10.P$4
unnamed: TET5.P$31, TET11.P$1
unnamed: TET5.P$30, TET11.P$2
unnamed: TET5.P$29, TET11.P$3
unnamed: TET5.P$12, TET14.P$2
unnamed: TET5.P$13, TET14.P$1
unnamed: TET5.P$14, TET15.P$4
unnamed: TET5.P$15, TET15.P$3
unnamed: TET5.P$16, TET15.P$2
unnamed: TET5.P$17, TET15.P$1
unnamed: TET1.P$4, TET4.P$2
unnamed: TET1.P$3, TET4.P$3
unnamed: TET1.P$2, TET4.P$4
unnamed: TET1.P$1, TET4.P$5
unnamed: TET0.P$4, TET4.P$6
unnamed: TET0.P$3, TET4.P$7
unnamed: TET0.P$2, TET4.P$8
unnamed: TET0.P$1, TET4.P$9
unnamed: TET3.P$1, TET4.P$35
unnamed: TET3.P$2, TET4.P$34
unnamed: TET3.P$3, TET4.P$33
unnamed: TET3.P$4, TET4.P$32
unnamed: TET2.P$1, TET4.P$31
unnamed: TET2.P$2, TET4.P$30
unnamed: TET5.P$20, TET13.P$4
unnamed: TET2.P$4, TET4.P$28
unnamed: TET4.P$27, TET21.P$1
unnamed: TET4.P$25, TET21.P$3
unnamed: TET4.P$26, TET21.P$2
unnamed: TET4.P$24, TET21.P$4
unnamed: TET4.P$23, TET20.P$1
unnamed: TET4.P$22, TET20.P$2
unnamed: TET4.P$21, TET20.P$3
unnamed: TET4.P$20, TET20.P$4
unnamed: TET4.P$10, TET23.P$4
unnamed: TET4.P$11, TET23.P$3
unnamed: TET4.P$12, TET23.P$2
unnamed: TET4.P$13, TET23.P$1
unnamed: TET4.P$14, TET22.P$4
unnamed: TET4.P$15, TET22.P$3
unnamed: TET4.P$16, TET22.P$2
unnamed: TET4.P$17, TET22.P$1
unnamed: TET2.P$3, TET4.P$29
REF: TET4.P$18, TET4.P$36, TET5.P$18, TET5.P$36

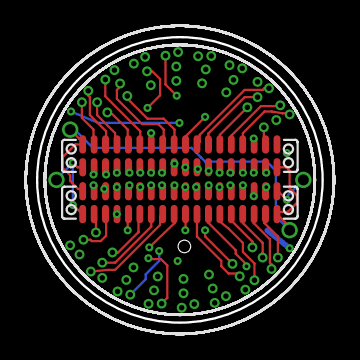
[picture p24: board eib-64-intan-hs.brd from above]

Board: 4 copper layers, 15.9 x 15.9 mm, 18 parts (0 on the bottom side), 66 nets.

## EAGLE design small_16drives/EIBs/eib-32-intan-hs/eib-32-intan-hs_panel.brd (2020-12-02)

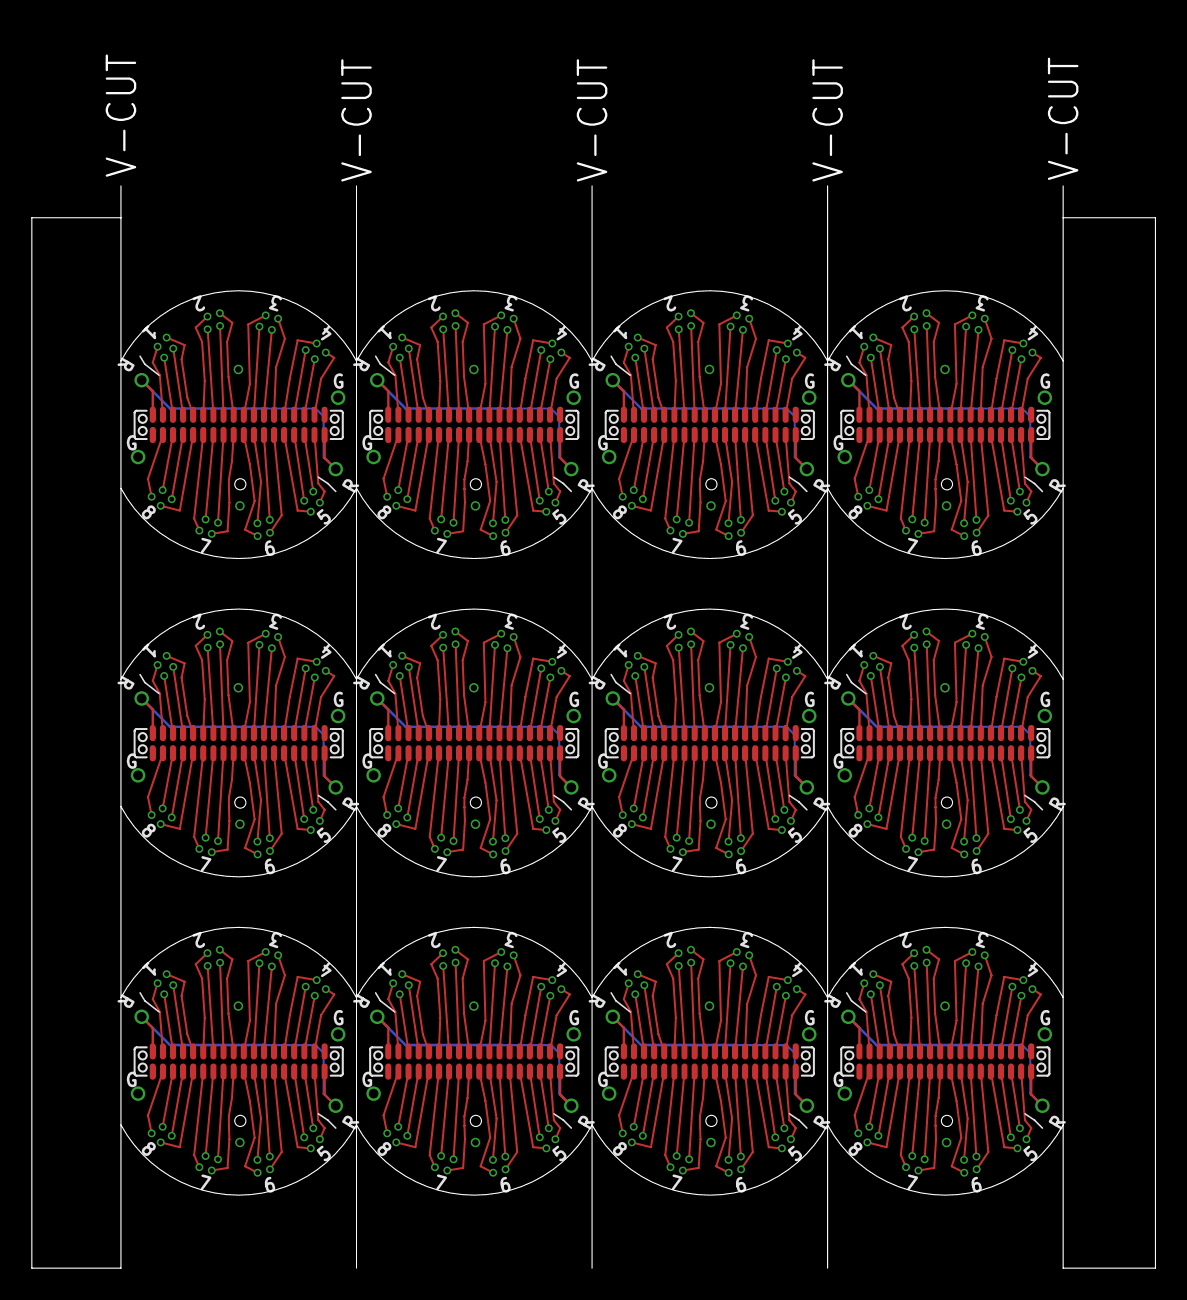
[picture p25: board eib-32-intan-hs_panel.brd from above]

Board: 2 copper layers, 70.6 x 68.0 mm, 108 parts (0 on the bottom side), 397 nets.

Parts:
J1, J2, J3, J4, J5, J6, J7, J8, J9, J10, J11, J12: 4; NPD-36-VV-GS
TET1, TET9, TET17, TET25, TET33, TET41, TET49, TET57, TET64, TET73, TET81, TET89: 0; TET8
TET2, TET10, TET18, TET26, TET34, TET42, TET50, TET58, TET65, TET74, TET82, TET90: 1; TET8
TET3, TET11, TET19, TET27, TET35, TET43, TET51, TET59, TET66, TET75, TET83, TET91: 4; TET8
TET4, TET12, TET20, TET28, TET36, TET44, TET52, TET60, TET67, TET76, TET84, TET92: 5; TET8
TET5, TET13, TET21, TET29, TET37, TET45, TET53, TET61, TET68, TET77, TET85, TET93: 6; TET8
TET6, TET14, TET22, TET30, TET38, TET46, TET54, TET62, TET69, TET78, TET86, TET94: 7; TET8
TET7, TET15, TET23, TET31, TET39, TET47, TET55, TET63, TET70, TET79, TET87, TET95: 10; TET8
TET8, TET16, TET24, TET32, TET40, TET48, TET56, TET71, TET72, TET80, TET88, TET96: 11; TET8

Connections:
GND: J1.P$1, J1.P$19, J2.P$1, J2.P$19, J3.P$1, J3.P$19, J4.P$1, J4.P$19, J5.P$1, J5.P$19, J6.P$1, J6.P$19, J7.P$1, J7.P$19, J8.P$1, J8.P$19, J9.P$1, J9.P$19, J10.P$1, J10.P$19, J11.P$1, J11.P$19, J12.P$1, J12.P$19
unnamed: J1.P$35, TET2.P$1
unnamed: J1.P$32, TET2.P$2
unnamed: J1.P$33, TET2.P$3
unnamed: J1.P$34, TET2.P$4
unnamed: J1.P$28, TET1.P$2
unnamed: J1.P$30, TET1.P$4
unnamed: J1.P$29, TET1.P$3
unnamed: J1.P$31, TET1.P$1
unnamed: J1.P$27, TET8.P$1
unnamed: J1.P$24, TET8.P$2
unnamed: J1.P$26, TET8.P$4
unnamed: J1.P$25, TET8.P$3
unnamed: J1.P$23, TET7.P$1
unnamed: J1.P$20, TET7.P$2
unnamed: J1.P$22, TET7.P$4
unnamed: J1.P$21, TET7.P$3
unnamed: J1.P$17, TET6.P$1
unnamed: J1.P$14, TET6.P$2
unnamed: J1.P$16, TET6.P$4
unnamed: J1.P$15, TET6.P$3
unnamed: J1.P$13, TET5.P$1
unnamed: J1.P$9, TET4.P$1
unnamed: J1.P$5, TET3.P$1
unnamed: J1.P$10, TET5.P$2
unnamed: J1.P$12, TET5.P$4
unnamed: J1.P$11, TET5.P$3
unnamed: J1.P$7, TET4.P$3
unnamed: J1.P$8, TET4.P$4
unnamed: J1.P$6, TET4.P$2
unnamed: J1.P$3, TET3.P$3
unnamed: J1.P$4, TET3.P$4
unnamed: J1.P$2, TET3.P$2
unnamed: J2.P$35, TET10.P$1
unnamed: J2.P$32, TET10.P$2
unnamed: J2.P$33, TET10.P$3
unnamed: J2.P$34, TET10.P$4
unnamed: J2.P$28, TET9.P$2
unnamed: J2.P$30, TET9.P$4
unnamed: J2.P$29, TET9.P$3
unnamed: J2.P$31, TET9.P$1
unnamed: J2.P$27, TET16.P$1
unnamed: J2.P$24, TET16.P$2
unnamed: J2.P$26, TET16.P$4
unnamed: J2.P$25, TET16.P$3
unnamed: J2.P$23, TET15.P$1
unnamed: J2.P$20, TET15.P$2
unnamed: J2.P$22, TET15.P$4
unnamed: J2.P$21, TET15.P$3
unnamed: J2.P$17, TET14.P$1
unnamed: J2.P$14, TET14.P$2
unnamed: J2.P$16, TET14.P$4
unnamed: J2.P$15, TET14.P$3
unnamed: J2.P$13, TET13.P$1
unnamed: J2.P$9, TET12.P$1
unnamed: J2.P$5, TET11.P$1
unnamed: J2.P$10, TET13.P$2
unnamed: J2.P$12, TET13.P$4
unnamed: J2.P$11, TET13.P$3
unnamed: J2.P$7, TET12.P$3
unnamed: J2.P$8, TET12.P$4
unnamed: J2.P$6, TET12.P$2
unnamed: J2.P$3, TET11.P$3
unnamed: J2.P$4, TET11.P$4
unnamed: J2.P$2, TET11.P$2
unnamed: J3.P$35, TET18.P$1
unnamed: J3.P$32, TET18.P$2
unnamed: J3.P$33, TET18.P$3
unnamed: J3.P$34, TET18.P$4
unnamed: J3.P$28, TET17.P$2
unnamed: J3.P$30, TET17.P$4
unnamed: J3.P$29, TET17.P$3
unnamed: J3.P$31, TET17.P$1
unnamed: J3.P$27, TET24.P$1
unnamed: J3.P$24, TET24.P$2
unnamed: J3.P$26, TET24.P$4
unnamed: J3.P$25, TET24.P$3
unnamed: J3.P$23, TET23.P$1
unnamed: J3.P$20, TET23.P$2
unnamed: J3.P$22, TET23.P$4
unnamed: J3.P$21, TET23.P$3
unnamed: J3.P$17, TET22.P$1
unnamed: J3.P$14, TET22.P$2
unnamed: J3.P$16, TET22.P$4
unnamed: J3.P$15, TET22.P$3
unnamed: J3.P$13, TET21.P$1
unnamed: J3.P$9, TET20.P$1
unnamed: J3.P$5, TET19.P$1
unnamed: J3.P$10, TET21.P$2
unnamed: J3.P$12, TET21.P$4
unnamed: J3.P$11, TET21.P$3
unnamed: J3.P$7, TET20.P$3
unnamed: J3.P$8, TET20.P$4
unnamed: J3.P$6, TET20.P$2
unnamed: J3.P$3, TET19.P$3
unnamed: J3.P$4, TET19.P$4
unnamed: J3.P$2, TET19.P$2
unnamed: J4.P$35, TET26.P$1
unnamed: J4.P$32, TET26.P$2
unnamed: J4.P$33, TET26.P$3
unnamed: J4.P$34, TET26.P$4
unnamed: J4.P$28, TET25.P$2
unnamed: J4.P$30, TET25.P$4
unnamed: J4.P$29, TET25.P$3
unnamed: J4.P$31, TET25.P$1
unnamed: J4.P$27, TET32.P$1
unnamed: J4.P$24, TET32.P$2
unnamed: J4.P$26, TET32.P$4
unnamed: J4.P$25, TET32.P$3
unnamed: J4.P$23, TET31.P$1
unnamed: J4.P$20, TET31.P$2
unnamed: J4.P$22, TET31.P$4
unnamed: J4.P$21, TET31.P$3
unnamed: J4.P$17, TET30.P$1
unnamed: J4.P$14, TET30.P$2
unnamed: J4.P$16, TET30.P$4
unnamed: J4.P$15, TET30.P$3
unnamed: J4.P$13, TET29.P$1
unnamed: J4.P$9, TET28.P$1
unnamed: J4.P$5, TET27.P$1
unnamed: J4.P$10, TET29.P$2
unnamed: J4.P$12, TET29.P$4
unnamed: J4.P$11, TET29.P$3
unnamed: J4.P$7, TET28.P$3
unnamed: J4.P$8, TET28.P$4
unnamed: J4.P$6, TET28.P$2
unnamed: J4.P$3, TET27.P$3
unnamed: J4.P$4, TET27.P$4
unnamed: J4.P$2, TET27.P$2
unnamed: J6.P$35, TET34.P$1
unnamed: J6.P$32, TET34.P$2
unnamed: J6.P$33, TET34.P$3
unnamed: J6.P$34, TET34.P$4
unnamed: J6.P$28, TET33.P$2
unnamed: J6.P$30, TET33.P$4
unnamed: J6.P$29, TET33.P$3
unnamed: J6.P$31, TET33.P$1
unnamed: J6.P$27, TET40.P$1
unnamed: J6.P$24, TET40.P$2
unnamed: J6.P$26, TET40.P$4
unnamed: J6.P$25, TET40.P$3
unnamed: J6.P$23, TET39.P$1
unnamed: J6.P$20, TET39.P$2
unnamed: J6.P$22, TET39.P$4
unnamed: J6.P$21, TET39.P$3
unnamed: J6.P$17, TET38.P$1
unnamed: J6.P$14, TET38.P$2
unnamed: J6.P$16, TET38.P$4
unnamed: J6.P$15, TET38.P$3
unnamed: J6.P$13, TET37.P$1
unnamed: J6.P$9, TET36.P$1
unnamed: J6.P$5, TET35.P$1
unnamed: J6.P$10, TET37.P$2
unnamed: J6.P$12, TET37.P$4
unnamed: J6.P$11, TET37.P$3
unnamed: J6.P$7, TET36.P$3
unnamed: J6.P$8, TET36.P$4
unnamed: J6.P$6, TET36.P$2
unnamed: J6.P$3, TET35.P$3
unnamed: J6.P$4, TET35.P$4
unnamed: J6.P$2, TET35.P$2
unnamed: J7.P$35, TET42.P$1
unnamed: J7.P$32, TET42.P$2
unnamed: J7.P$33, TET42.P$3
unnamed: J7.P$34, TET42.P$4
unnamed: J7.P$28, TET41.P$2
unnamed: J7.P$30, TET41.P$4
unnamed: J7.P$29, TET41.P$3
unnamed: J7.P$31, TET41.P$1
unnamed: J7.P$27, TET48.P$1
unnamed: J7.P$24, TET48.P$2
unnamed: J7.P$26, TET48.P$4
unnamed: J7.P$25, TET48.P$3
unnamed: J7.P$23, TET47.P$1
unnamed: J7.P$20, TET47.P$2
unnamed: J7.P$22, TET47.P$4
unnamed: J7.P$21, TET47.P$3
unnamed: J7.P$17, TET46.P$1
unnamed: J7.P$14, TET46.P$2
unnamed: J7.P$16, TET46.P$4
unnamed: J7.P$15, TET46.P$3
unnamed: J7.P$13, TET45.P$1
unnamed: J7.P$9, TET44.P$1
unnamed: J7.P$5, TET43.P$1
unnamed: J7.P$10, TET45.P$2
unnamed: J7.P$12, TET45.P$4
unnamed: J7.P$11, TET45.P$3
unnamed: J7.P$7, TET44.P$3
unnamed: J7.P$8, TET44.P$4
unnamed: J7.P$6, TET44.P$2
unnamed: J7.P$3, TET43.P$3
unnamed: J7.P$4, TET43.P$4
unnamed: J7.P$2, TET43.P$2
unnamed: J8.P$35, TET50.P$1
unnamed: J8.P$32, TET50.P$2
unnamed: J8.P$33, TET50.P$3
unnamed: J8.P$34, TET50.P$4
unnamed: J8.P$28, TET49.P$2
unnamed: J8.P$30, TET49.P$4
unnamed: J8.P$29, TET49.P$3
unnamed: J8.P$31, TET49.P$1
unnamed: J8.P$27, TET56.P$1
unnamed: J8.P$24, TET56.P$2
unnamed: J8.P$26, TET56.P$4
unnamed: J8.P$25, TET56.P$3
unnamed: J8.P$23, TET55.P$1
unnamed: J8.P$20, TET55.P$2
unnamed: J8.P$22, TET55.P$4
unnamed: J8.P$21, TET55.P$3
unnamed: J8.P$17, TET54.P$1
unnamed: J8.P$14, TET54.P$2
unnamed: J8.P$16, TET54.P$4
unnamed: J8.P$15, TET54.P$3
unnamed: J8.P$13, TET53.P$1
unnamed: J8.P$9, TET52.P$1
unnamed: J8.P$5, TET51.P$1
unnamed: J8.P$10, TET53.P$2
unnamed: J8.P$12, TET53.P$4
unnamed: J8.P$11, TET53.P$3
unnamed: J8.P$7, TET52.P$3
unnamed: J8.P$8, TET52.P$4
unnamed: J8.P$6, TET52.P$2
unnamed: J8.P$3, TET51.P$3
unnamed: J8.P$4, TET51.P$4
unnamed: J8.P$2, TET51.P$2
unnamed: J9.P$35, TET58.P$1
unnamed: J9.P$32, TET58.P$2
unnamed: J9.P$33, TET58.P$3
unnamed: J9.P$34, TET58.P$4
unnamed: J9.P$28, TET57.P$2
unnamed: J9.P$30, TET57.P$4
unnamed: J9.P$29, TET57.P$3
unnamed: J9.P$31, TET57.P$1
unnamed: J9.P$27, TET72.P$1
unnamed: J9.P$24, TET72.P$2
unnamed: J9.P$26, TET72.P$4
unnamed: J9.P$25, TET72.P$3
unnamed: J9.P$23, TET63.P$1
unnamed: J9.P$20, TET63.P$2
unnamed: J9.P$22, TET63.P$4
unnamed: J9.P$21, TET63.P$3
unnamed: J9.P$17, TET62.P$1
unnamed: J9.P$14, TET62.P$2
unnamed: J9.P$16, TET62.P$4
unnamed: J9.P$15, TET62.P$3
unnamed: J9.P$13, TET61.P$1
unnamed: J9.P$9, TET60.P$1
unnamed: J9.P$5, TET59.P$1
unnamed: J9.P$10, TET61.P$2
unnamed: J9.P$12, TET61.P$4
unnamed: J9.P$11, TET61.P$3
unnamed: J9.P$7, TET60.P$3
unnamed: J9.P$8, TET60.P$4
unnamed: J9.P$6, TET60.P$2
unnamed: J9.P$3, TET59.P$3
unnamed: J9.P$4, TET59.P$4
unnamed: J9.P$2, TET59.P$2
unnamed: J5.P$35, TET65.P$1
unnamed: J5.P$32, TET65.P$2
unnamed: J5.P$33, TET65.P$3
unnamed: J5.P$34, TET65.P$4
unnamed: J5.P$28, TET64.P$2
unnamed: J5.P$30, TET64.P$4
unnamed: J5.P$29, TET64.P$3
unnamed: J5.P$31, TET64.P$1
unnamed: J5.P$27, TET71.P$1
unnamed: J5.P$24, TET71.P$2
unnamed: J5.P$26, TET71.P$4
unnamed: J5.P$25, TET71.P$3
unnamed: J5.P$23, TET70.P$1
unnamed: J5.P$20, TET70.P$2
unnamed: J5.P$22, TET70.P$4
unnamed: J5.P$21, TET70.P$3
unnamed: J5.P$17, TET69.P$1
unnamed: J5.P$14, TET69.P$2
unnamed: J5.P$16, TET69.P$4
unnamed: J5.P$15, TET69.P$3
unnamed: J5.P$13, TET68.P$1
unnamed: J5.P$9, TET67.P$1
unnamed: J5.P$5, TET66.P$1
unnamed: J5.P$10, TET68.P$2
unnamed: J5.P$12, TET68.P$4
unnamed: J5.P$11, TET68.P$3
unnamed: J5.P$7, TET67.P$3
unnamed: J5.P$8, TET67.P$4
unnamed: J5.P$6, TET67.P$2
unnamed: J5.P$3, TET66.P$3
unnamed: J5.P$4, TET66.P$4
unnamed: J5.P$2, TET66.P$2
unnamed: J10.P$35, TET74.P$1
unnamed: J10.P$32, TET74.P$2
unnamed: J10.P$33, TET74.P$3
unnamed: J10.P$34, TET74.P$4
unnamed: J10.P$28, TET73.P$2
unnamed: J10.P$30, TET73.P$4
unnamed: J10.P$29, TET73.P$3
unnamed: J10.P$31, TET73.P$1
unnamed: J10.P$27, TET80.P$1
unnamed: J10.P$24, TET80.P$2
unnamed: J10.P$26, TET80.P$4
unnamed: J10.P$25, TET80.P$3
unnamed: J10.P$23, TET79.P$1
unnamed: J10.P$20, TET79.P$2
unnamed: J10.P$22, TET79.P$4
unnamed: J10.P$21, TET79.P$3
unnamed: J10.P$17, TET78.P$1
unnamed: J10.P$14, TET78.P$2
unnamed: J10.P$16, TET78.P$4
unnamed: J10.P$15, TET78.P$3
unnamed: J10.P$13, TET77.P$1
unnamed: J10.P$9, TET76.P$1
unnamed: J10.P$5, TET75.P$1
unnamed: J10.P$10, TET77.P$2
unnamed: J10.P$12, TET77.P$4
unnamed: J10.P$11, TET77.P$3
unnamed: J10.P$7, TET76.P$3
unnamed: J10.P$8, TET76.P$4
unnamed: J10.P$6, TET76.P$2
unnamed: J10.P$3, TET75.P$3
unnamed: J10.P$4, TET75.P$4
unnamed: J10.P$2, TET75.P$2
unnamed: J11.P$35, TET82.P$1
unnamed: J11.P$32, TET82.P$2
unnamed: J11.P$33, TET82.P$3
unnamed: J11.P$34, TET82.P$4
unnamed: J11.P$28, TET81.P$2
unnamed: J11.P$30, TET81.P$4
unnamed: J11.P$29, TET81.P$3
unnamed: J11.P$31, TET81.P$1
unnamed: J11.P$27, TET88.P$1
unnamed: J11.P$24, TET88.P$2
unnamed: J11.P$26, TET88.P$4
unnamed: J11.P$25, TET88.P$3
unnamed: J11.P$23, TET87.P$1
unnamed: J11.P$20, TET87.P$2
unnamed: J11.P$22, TET87.P$4
unnamed: J11.P$21, TET87.P$3
unnamed: J11.P$17, TET86.P$1
unnamed: J11.P$14, TET86.P$2
unnamed: J11.P$16, TET86.P$4
unnamed: J11.P$15, TET86.P$3
unnamed: J11.P$13, TET85.P$1
unnamed: J11.P$9, TET84.P$1
unnamed: J11.P$5, TET83.P$1
unnamed: J11.P$10, TET85.P$2
unnamed: J11.P$12, TET85.P$4
unnamed: J11.P$11, TET85.P$3
unnamed: J11.P$7, TET84.P$3
unnamed: J11.P$8, TET84.P$4
unnamed: J11.P$6, TET84.P$2
unnamed: J11.P$3, TET83.P$3
unnamed: J11.P$4, TET83.P$4
unnamed: J11.P$2, TET83.P$2
unnamed: J12.P$35, TET90.P$1
unnamed: J12.P$32, TET90.P$2
unnamed: J12.P$33, TET90.P$3
unnamed: J12.P$34, TET90.P$4
unnamed: J12.P$28, TET89.P$2
unnamed: J12.P$30, TET89.P$4
unnamed: J12.P$29, TET89.P$3
unnamed: J12.P$31, TET89.P$1
unnamed: J12.P$27, TET96.P$1
unnamed: J12.P$24, TET96.P$2
unnamed: J12.P$26, TET96.P$4
unnamed: J12.P$25, TET96.P$3
unnamed: J12.P$23, TET95.P$1
unnamed: J12.P$20, TET95.P$2
unnamed: J12.P$22, TET95.P$4
unnamed: J12.P$21, TET95.P$3
unnamed: J12.P$17, TET94.P$1
unnamed: J12.P$14, TET94.P$2
unnamed: J12.P$16, TET94.P$4
unnamed: J12.P$15, TET94.P$3
unnamed: J12.P$13, TET93.P$1
unnamed: J12.P$9, TET92.P$1
unnamed: J12.P$5, TET91.P$1
unnamed: J12.P$10, TET93.P$2
unnamed: J12.P$12, TET93.P$4
unnamed: J12.P$11, TET93.P$3
unnamed: J12.P$7, TET92.P$3
unnamed: J12.P$8, TET92.P$4
unnamed: J12.P$6, TET92.P$2
unnamed: J12.P$3, TET91.P$3
unnamed: J12.P$4, TET91.P$4
unnamed: J12.P$2, TET91.P$2
REF1: J1.P$18, J1.P$36
REF2: J2.P$18, J2.P$36
REF3: J3.P$18, J3.P$36
REF4: J5.P$18, J5.P$36
REF5: J4.P$18, J4.P$36
REF6: J6.P$18, J6.P$36
REF7: J7.P$18, J7.P$36
REF8: J8.P$18, J8.P$36
REF9: J9.P$18, J9.P$36
REF10: J10.P$18, J10.P$36
REF11: J11.P$18, J11.P$36
REF12: J12.P$18, J12.P$36

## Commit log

2019-08-23 updated readme
    added more info and link to BOM
2019-08-24 initial commit mouse drive
    [3d_printed_guide_array.SLDPRT, dowel pin_a_jis.sldprt, drive_holder_bottom.SLDPRT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]
2019-09-19 Cleanup repo metadata
    - Numerous fixes to README. Typos, etc.
    - Add proper license materials to repo
2019-09-19 Added large drive design files to repo
    [CONSMA001-ND.SLDPRT, rat-eib.SLDPRT, rat-headstage.SLDPRT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]
2019-11-07 added screw designs
2019-11-18 added rat drive jig
    [50mm_4mm_dowel.SLDPRT, 80mm_6mm_dowel.SLDPRT, 91290A201_BLACK-OXIDE CLASS 12.9 SOCKET HEAD CAP SCREW.SLDPRT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]
2020-07-01 added bilaterral variant
    [shuttle_drive_body_bilateral_square_3_5mm_gap.SLDPRT, shuttle_drive_body_bilateral_square_3_5mm_gap.STL]
2020-12-02 Added old omnetics EIB designs
    [eib-32-intan-hs.brd, eib-32-intan-hs.sch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]
2021-01-29 Updated EIB holders for jig
    now has 2 options for large and small offsets
    [eib_holder_inner_hirose_1mm_offset.SLDPRT, eib_holder_inner_hirose_1mm_offset.STL, eib_holder_inner_hirose_2mm_offset.SLDPRT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]

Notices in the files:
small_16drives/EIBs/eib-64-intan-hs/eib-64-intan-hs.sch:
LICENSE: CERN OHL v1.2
